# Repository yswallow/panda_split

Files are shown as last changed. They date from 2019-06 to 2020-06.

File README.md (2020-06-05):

# パンダスルーホール
split 5x4 keyboard using MCP23017

## Parts (one hand)

| name | number | description | site | substitute |
| ---- | ---- | ---- | ---- | ---- |
| MJ-4PP-9 | 2 | TRRS jack | http://akizukidenshi.com/catalog/g/gC-06070/ | PJ-320A |
| LED| 1 |  |  |  |
| Resistor | 1 | for LED | http://akizukidenshi.com/catalog/g/gR-25472/ |  |
| Capacitor 0.1μF | 1 | 2.5mm pitch | http://akizukidenshi.com/catalog/g/gP-00090/ |  |
| Slide Switch | 2 | 2.54mm pitch, SPDT | http://akizukidenshi.com/catalog/g/gP-08790/ |  |
| MCP23017-E/SP | 2 | I2C I/O Expander | http://akizukidenshi.com/catalog/g/gI-09486/ |  |
| IC Socket | 2 | 28pin, 300mil | http://akizukidenshi.com/catalog/g/gP-00013/ |  |
| M3x10mm Screw | 4 |  |  |  |
| M3 nut | 4 |  |  |  |
| rubber feet | 4 | >4mm thick |  |  |
| Kailh Socket | 20 | choc or MX |  |  |
| Keyboard Switch | 20 | choc or MX |  |  |

and PCB, Top/Bottom Plate, panda-pendant, 2 trrs cable.

## Build log (not using top/bottom plate)
http://y-sni.hatenablog.com/entry/2019/03/08/170233

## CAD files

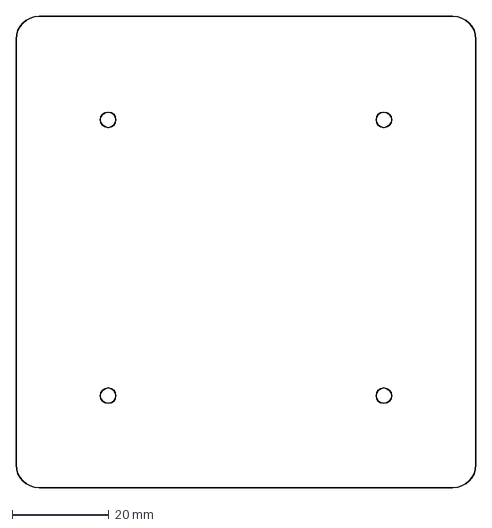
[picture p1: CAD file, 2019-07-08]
dxf/bottom.dxf
95.2 x 97.6 mm

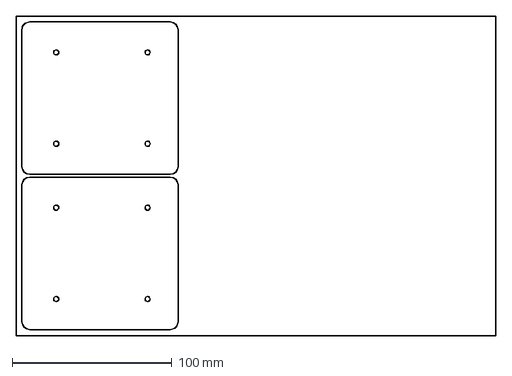
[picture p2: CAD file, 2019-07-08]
dxf/cut.dxf
300.0 x 200.0 mm

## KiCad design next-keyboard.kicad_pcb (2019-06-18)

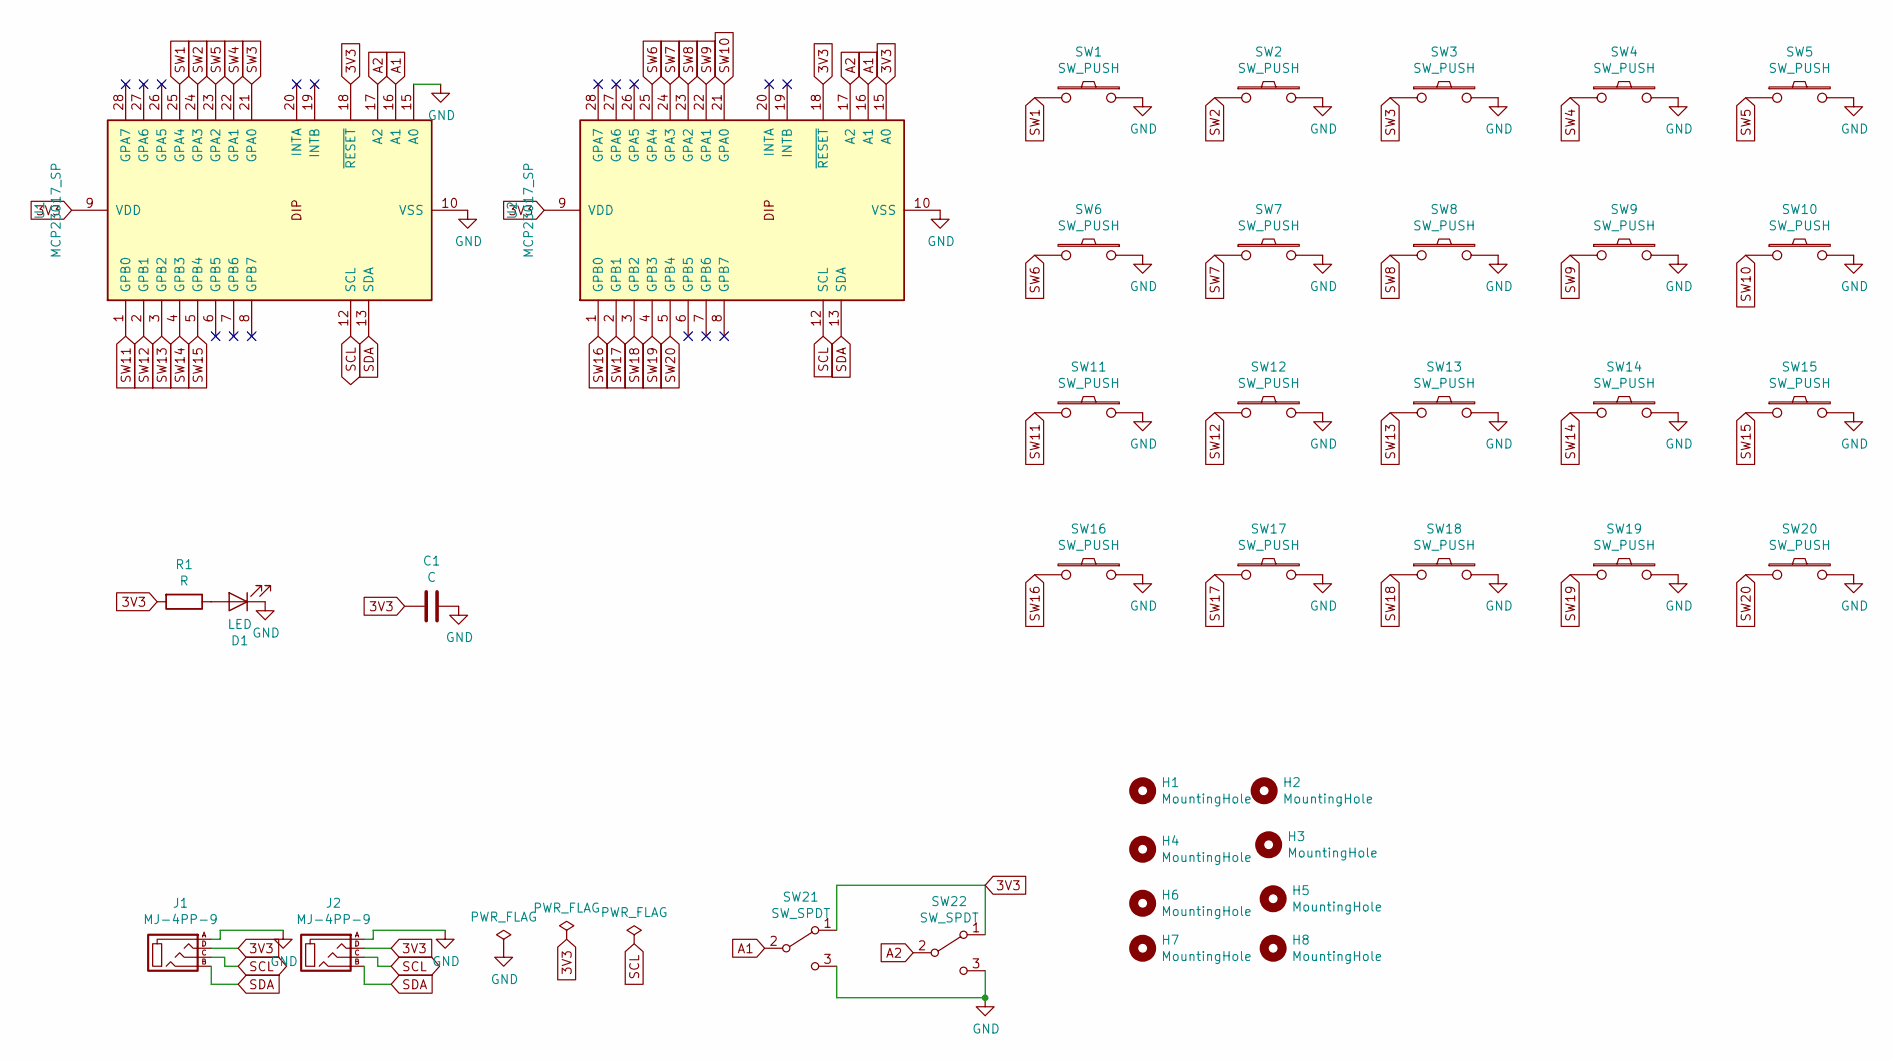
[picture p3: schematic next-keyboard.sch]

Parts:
C1: C; C_Disc_D3.8mm_W2.6mm_P2.50mm
D1: LED; LED_D3.0mm
H1, H2, H3, H4: MountingHole; MountingHole_3.2mm_M3
H5, H6, H7, H8: MountingHole; HOLE
J1, J2: MJ-4PP-9
R1: R; R_Axial_DIN0207_L6.3mm_D2.5mm_P7.62mm_Horizontal
SW1, SW2, SW3, SW4, SW5, SW6, SW7, SW8, SW9, SW10, SW11, SW12, SW13, SW14, SW15, SW16, SW17, SW18, SW19, SW20: SW_PUSH; CherryMX_KailhLowProfile_Hotswap_singleside_5pin
SW21, SW22: SW_SPDT; SlideSwitch_SS-12D00
U1, U2: MCP23017_SP; DIP-28_W7.62mm_Socket

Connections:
3V3: C1.2, J1.D, J2.D, R1.2, SW21.1 (A), SW22.1 (A), U1.9 (VDD), U1.18 (~RESET~), U2.9 (VDD), U2.15 (A0), U2.18 (~RESET~)
A1: SW21.2 (B), U1.16 (A1), U2.16 (A1)
A2: SW22.2 (B), U1.17 (A2), U2.17 (A2)
GND: C1.1, D1.1 (K), J1.A, J2.A, SW1.1, SW2.2, SW3.2, SW4.2, SW5.2, SW6.1, SW7.2, SW8.2, SW9.2, SW10.2, SW11.1, SW12.2, SW13.2, SW14.2, SW15.2, SW16.1, SW17.2, SW18.2, SW19.2, SW20.2, SW21.3 (C), SW22.3 (C), U1.10 (VSS), U1.15 (A0), U2.10 (VSS)
unnamed: D1.2 (A), R1.1
SCL: J1.C, J2.C, U1.12 (SCL), U2.12 (SCL)
SDA: J1.B, J2.B, U1.13 (SDA), U2.13 (SDA)
SW1: SW1.2, U1.25 (GPA4)
SW2: SW2.1, U1.24 (GPA3)
SW3: SW3.1, U1.21 (GPA0)
SW4: SW4.1, U1.22 (GPA1)
SW5: SW5.1, U1.23 (GPA2)
SW6: SW6.2, U2.25 (GPA4)
SW7: SW7.1, U2.24 (GPA3)
SW8: SW8.1, U2.23 (GPA2)
SW9: SW9.1, U2.22 (GPA1)
SW10: SW10.1, U2.21 (GPA0)
SW11: SW11.2, U1.1 (GPB0)
SW12: SW12.1, U1.2 (GPB1)
SW13: SW13.1, U1.3 (GPB2)
SW14: SW14.1, U1.4 (GPB3)
SW15: SW15.1, U1.5 (GPB4)
SW16: SW16.2, U2.1 (GPB0)
SW17: SW17.1, U2.2 (GPB1)
SW18: SW18.1, U2.3 (GPB2)
SW19: SW19.1, U2.4 (GPB3)
SW20: SW20.1, U2.5 (GPB4)

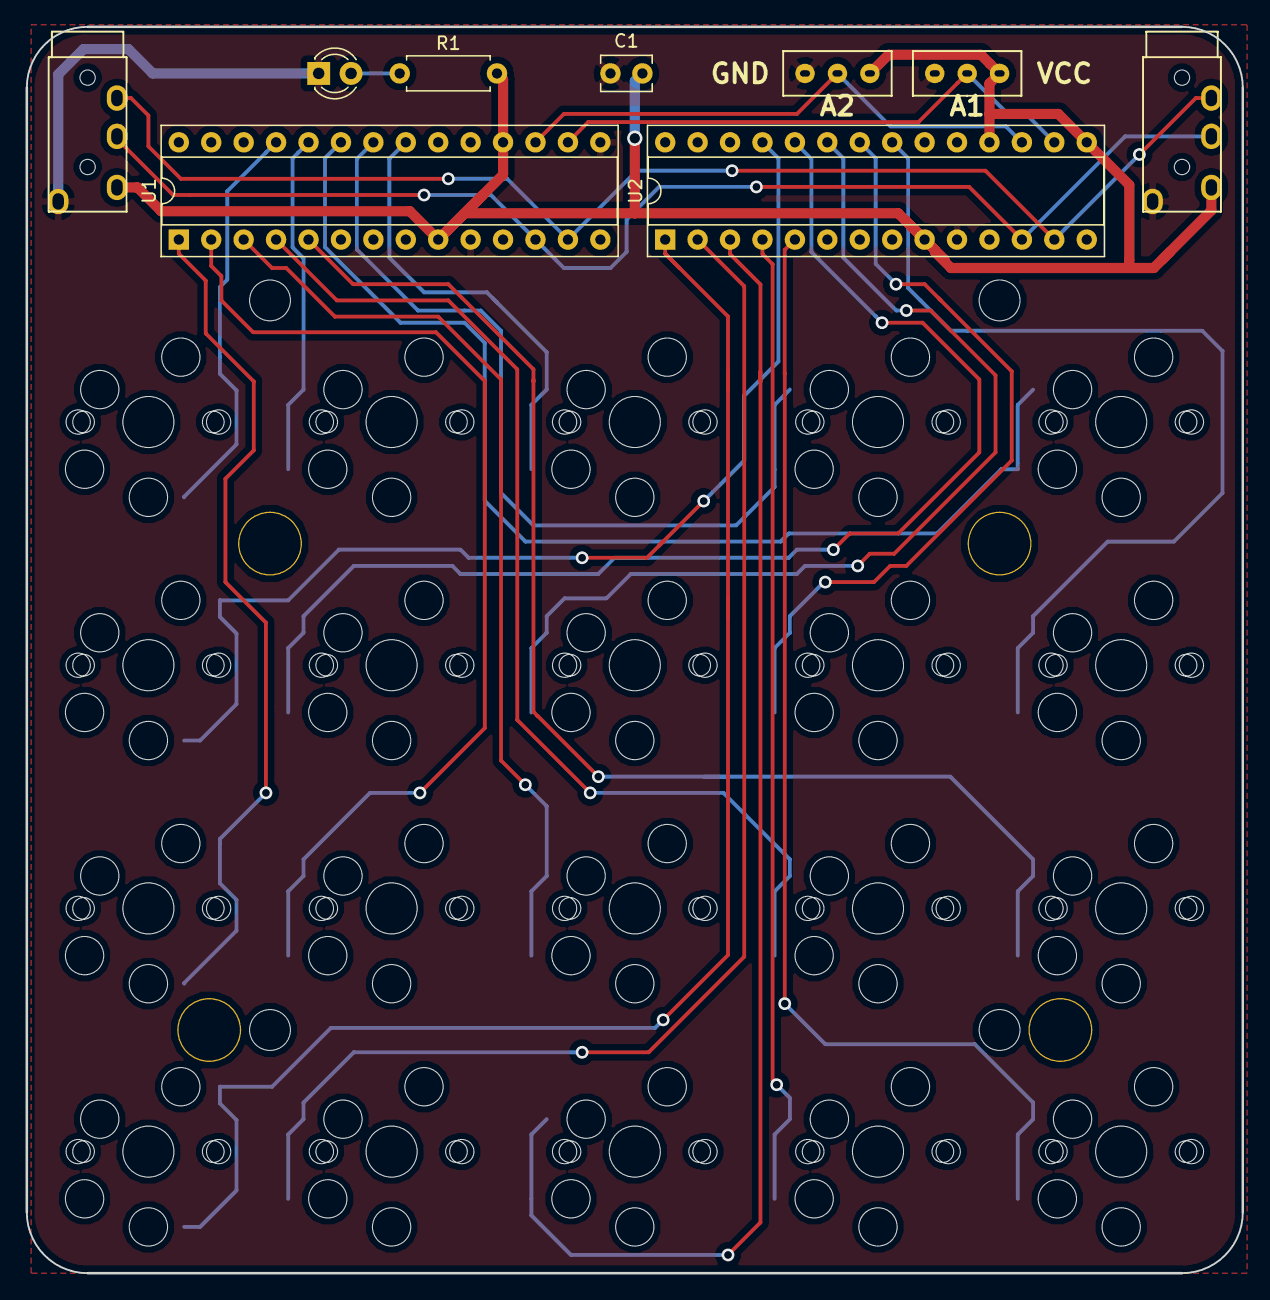
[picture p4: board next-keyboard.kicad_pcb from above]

Board: 2 copper layers, 95.2 x 97.6 mm, 37 parts (0 on the bottom side), 27 nets.
